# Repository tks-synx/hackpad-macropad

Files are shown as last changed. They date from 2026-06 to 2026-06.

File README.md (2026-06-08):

# hackpad-macropad

## Design Renders & Screenshots

### Macropad Design (Fusion)
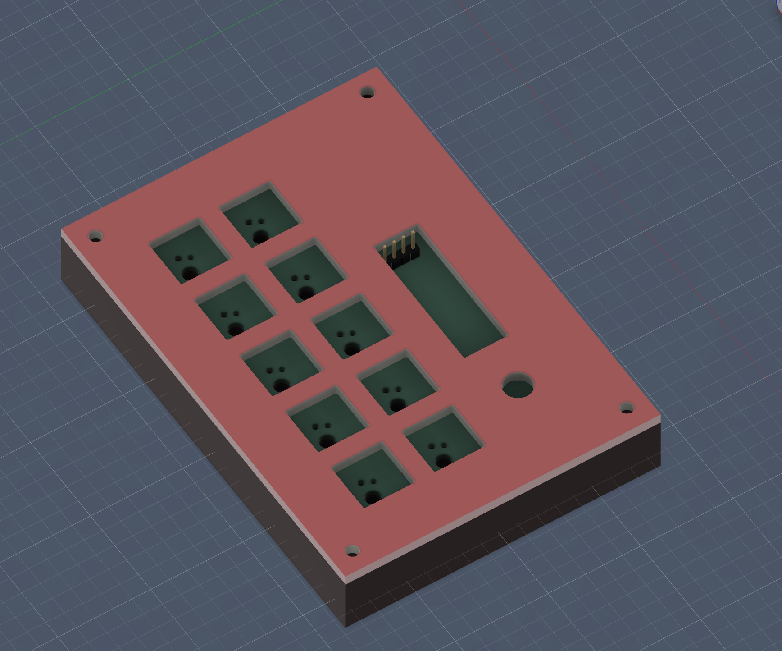
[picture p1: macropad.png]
Macropad Design

(Was not able to get the actual models for keycaps, switches, the OLED, rotator or MCU in Fusion)

### 3D Case Design (Fusion)
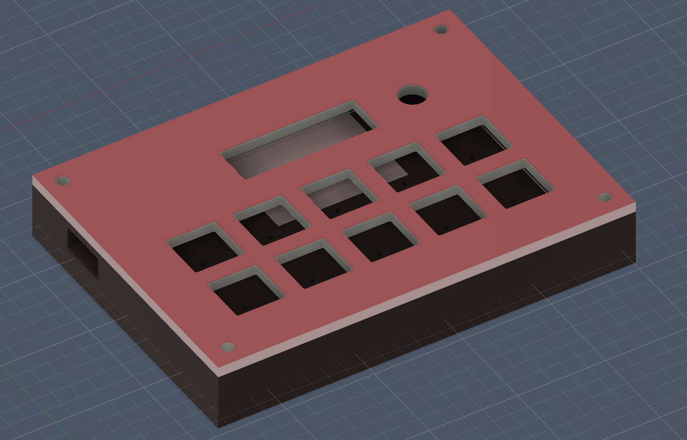
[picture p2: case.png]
Case Design


### Circuit Schematic (KiCad)
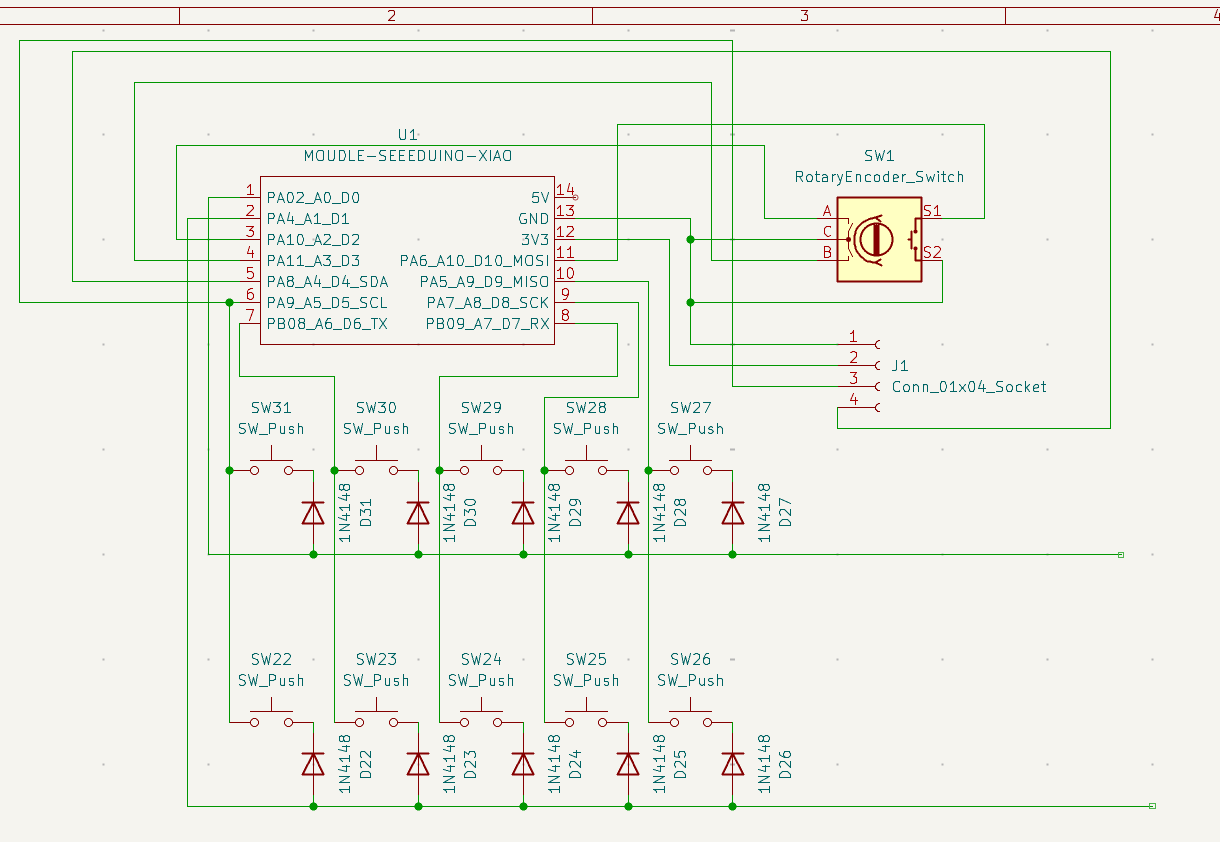
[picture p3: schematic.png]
Schematic


### PCB Layout (KiCad)
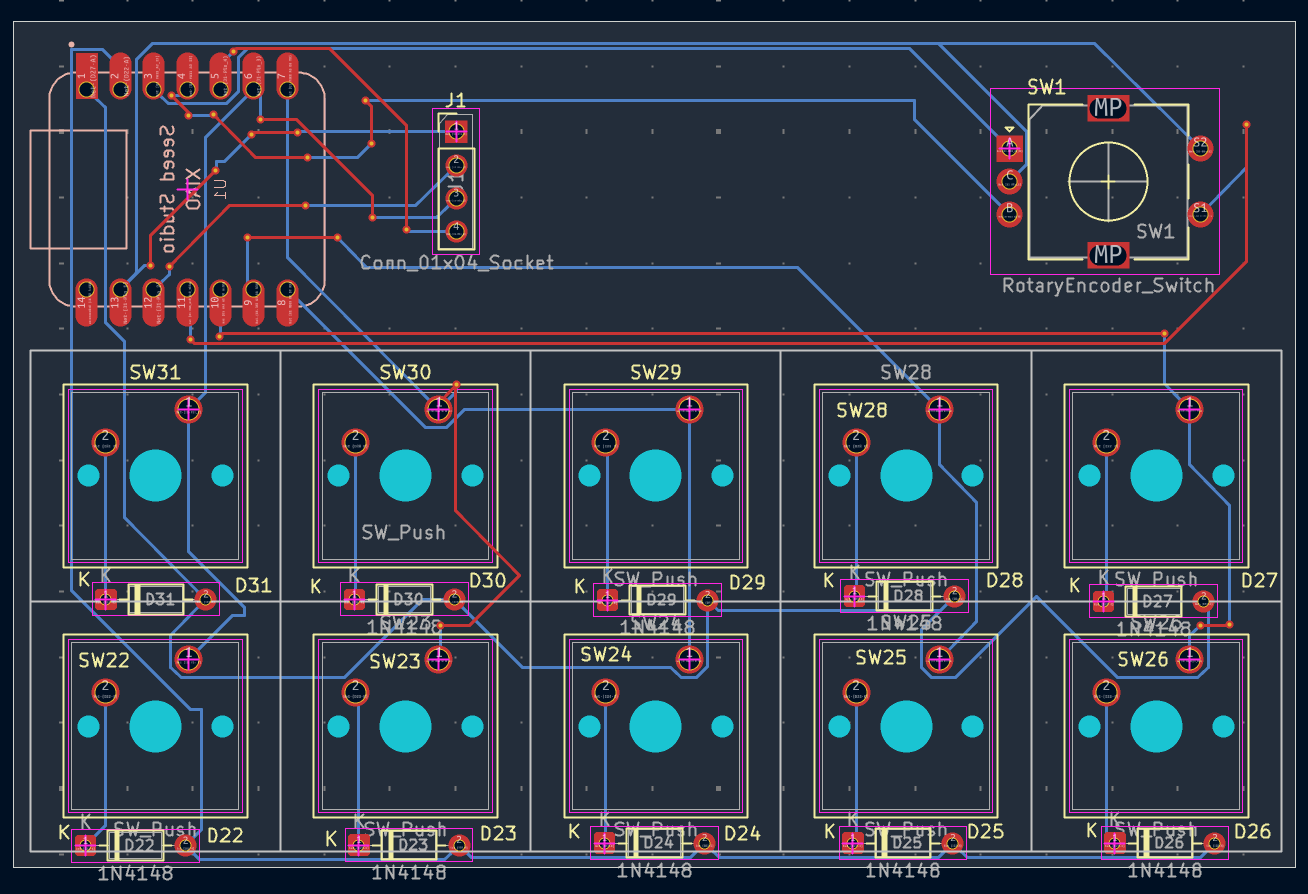
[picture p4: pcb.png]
PCB Layout


## Bill of Materials (BOM)
* [1]x Seeed XIAO RP2040 microcontroller
* [10]x MX-style mechanical switches
* [10]x Blank DSA keycaps
* [1]x 0.91” 128×32 OLED display 
* [1]x EC11 rotary encoders
* [4]x M3×16mm screws
* [4]x M3×5×4mm heatset inserts 
* 3D Printing Filament (PLA/PETG) In colour if possible

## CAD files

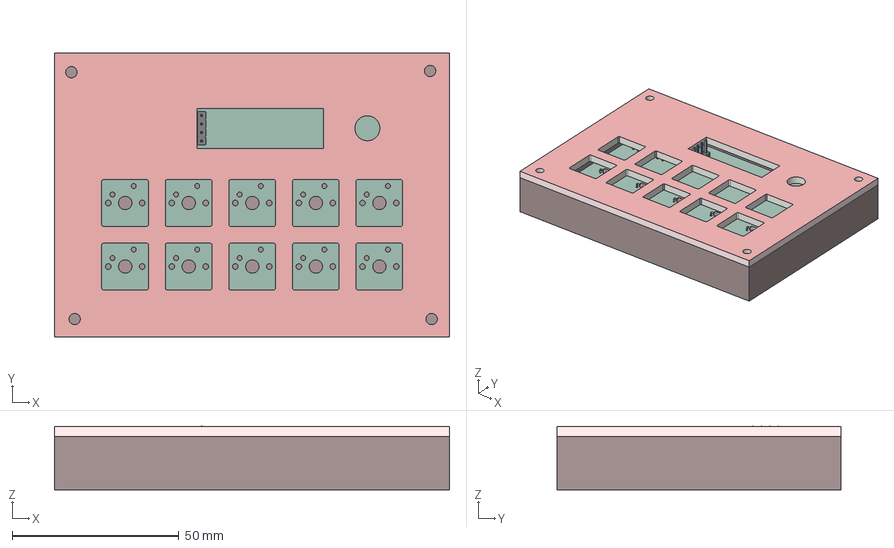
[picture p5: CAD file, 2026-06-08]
CAD/assembled-model.step
118.4 x 85.2 x 19.1 mm

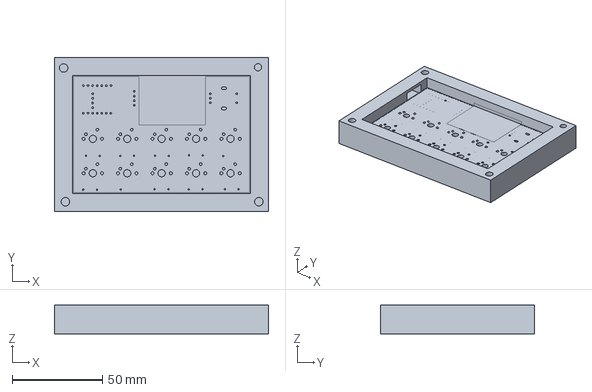
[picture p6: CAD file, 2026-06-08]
production/Bottom.step
118.4 x 85.2 x 16.0 mm

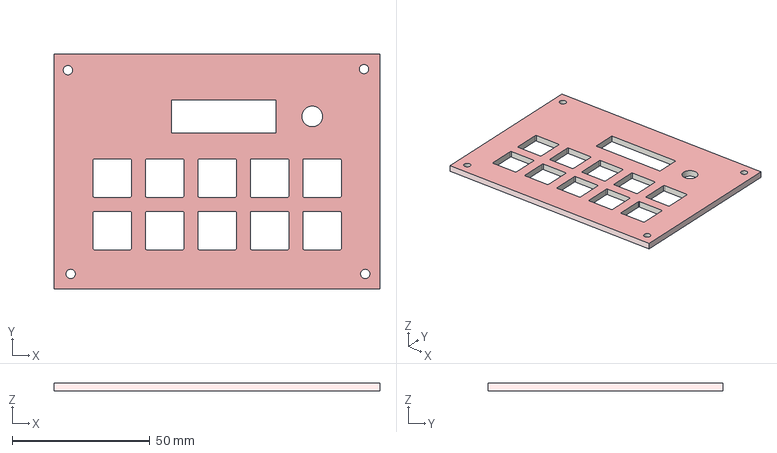
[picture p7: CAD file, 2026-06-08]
production/Top.step
118.4 x 85.2 x 3.00 mm

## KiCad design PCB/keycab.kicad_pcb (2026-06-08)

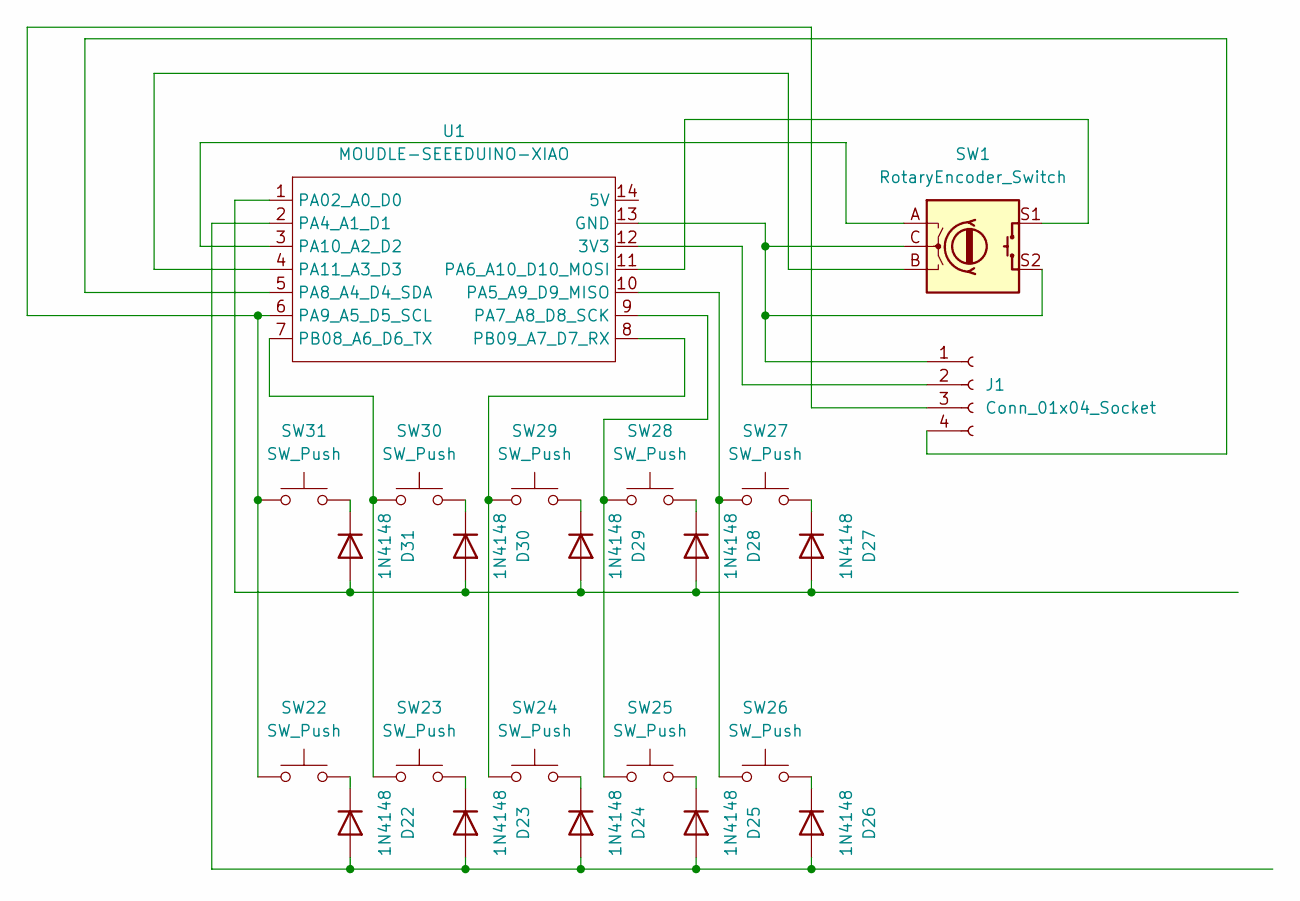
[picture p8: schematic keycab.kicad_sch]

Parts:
D22, D23, D24, D25, D26, D27, D28, D29, D30, D31: 1N4148; D_DO-35_SOD27_P7.62mm_Horizontal
J1: Conn_01x04_Socket; PinHeader_1x04_P2.54mm_Vertical
SW1: RotaryEncoder_Switch; RotaryEncoder_Alps_EC11E-Switch_Vertical_H20mm
SW22, SW23, SW24, SW25, SW26, SW27, SW28, SW29, SW30, SW31: SW_Push; SW_Cherry_MX_1.00u_PCB
U1: MOUDLE-SEEEDUINO-XIAO; XIAO-Generic-Hybrid-14P-2.54-21X17.8MM

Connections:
unnamed: D22.2 (A), D23.2 (A), D24.2 (A), D25.2 (A), D26.2 (A), U1.2 (PA4_A1_D1)
unnamed: D22.1 (K), SW22.2
unnamed: D23.1 (K), SW23.2
unnamed: D24.1 (K), SW24.2
unnamed: D25.1 (K), SW25.2
unnamed: D26.1 (K), SW26.2
unnamed: D27.2 (A), D28.2 (A), D29.2 (A), D30.2 (A), D31.2 (A), U1.1 (PA02_A0_D0)
unnamed: D27.1 (K), SW27.2
unnamed: D28.1 (K), SW28.2
unnamed: D29.1 (K), SW29.2
unnamed: D30.1 (K), SW30.2
unnamed: D31.1 (K), SW31.2
unnamed: J1.1, SW1.C, SW1.S2, U1.13 (GND)
unnamed: J1.2, U1.12 (3V3)
unnamed: J1.3, SW22.1, SW31.1, U1.6 (PA9_A5_D5_SCL)
unnamed: J1.4, U1.5 (PA8_A4_D4_SDA)
unnamed: SW26.1, SW27.1, U1.10 (PA5_A9_D9_MISO)
unnamed: SW1.S1, U1.11 (PA6_A10_D10_MOSI)
unnamed: SW25.1, SW28.1, U1.9 (PA7_A8_D8_SCK)
unnamed: SW1.A, U1.3 (PA10_A2_D2)
unnamed: SW1.B, U1.4 (PA11_A3_D3)
unnamed: SW23.1, SW30.1, U1.7 (PB08_A6_D6_TX)
unnamed: SW24.1, SW29.1, U1.8 (PB09_A7_D7_RX)

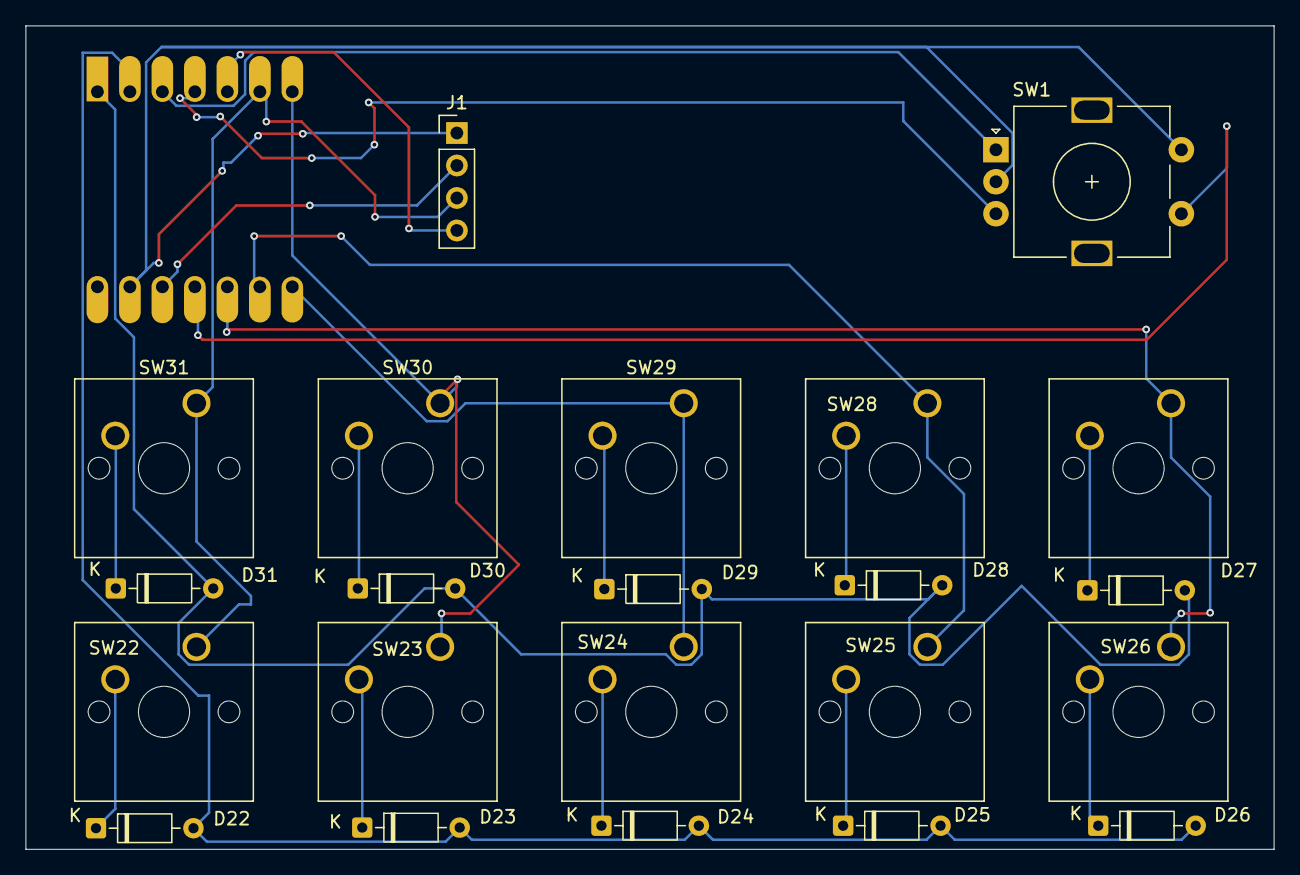
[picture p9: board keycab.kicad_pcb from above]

Board: 2 copper layers, 97.6 x 64.4 mm, 23 parts (1 on the bottom side), 23 nets.

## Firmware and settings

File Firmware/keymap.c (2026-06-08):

#include QMK_KEYBOARD_H
#include <stdio.h> // Required for sprintf formatting

/* ==========================================================================
   MACRO PAD MAC SIDE INSTALLATION & AUTOMATION BLUEPRINT
   
   PREREQUISITES:
   1. Open Terminal on your Mac and install the audio CLI tool via Homebrew:
      brew install switchaudio-source

   2. Open your favorite Mac automation utility (e.g., BetterTouchTool or 
      Keyboard Maestro) and build 5 separate triggers.

   ==========================================================================
   TRIGGER DETAILS & BASH SCRIPTS:
   ==========================================================================

   --- TRIGGER 1: KEY 10 (F13) - AUDIO DEVICE SWITCHER ---
   Type: Execute Shell Script
   Script:
      #!/bin/bash
      SwitchAudioSource -n
      NEW_DEV=$(SwitchAudioSource -c)
      XIAO_PORT=$(ls /dev/cu.usbmodem* 2>/dev/null | head -n 1)
      if [ ! -z "$XIAO_PORT" ]; then
          echo -ne "DEV:$NEW_DEV\r" > "$XIAO_PORT"
      fi

   --- TRIGGER 2: ENCODER CLOCKWISE (F14) - VOLUME UP ---
   Type: Execute Shell Script
   Script:
      #!/bin/bash
      osascript -e "set volume output volume ((output volume of (get audio status)) + 5)"
      NEW_VOL=$(osascript -e "output volume of (get audio status)")
      XIAO_PORT=$(ls /dev/cu.usbmodem* 2>/dev/null | head -n 1)
      if [ ! -z "$XIAO_PORT" ]; then
          echo -ne "VOL:$NEW_VOL%\r" > "$XIAO_PORT"
      fi

   --- TRIGGER 3: ENCODER COUNTER-CLOCKWISE (F15) - VOLUME DOWN ---
   Type: Execute Shell Script
   Script:
      #!/bin/bash
      osascript -e "set volume output volume ((output volume of (get audio status)) - 5)"
      NEW_VOL=$(osascript -e "output volume of (get audio status)")
      XIAO_PORT=$(ls /dev/cu.usbmodem* 2>/dev/null | head -n 1)
      if [ ! -z "$XIAO_PORT" ]; then
          echo -ne "VOL:$NEW_VOL%\r" > "$XIAO_PORT"
      fi

   --- TRIGGER 4: ENCODER CLOCKWISE (F16) - BRIGHTNESS UP ---
   Type: Execute Shell Script
   Script:
      #!/bin/bash
      osascript -e 'tell application "System Events" to key code 144'
      XIAO_PORT=$(ls /dev/cu.usbmodem* 2>/dev/null | head -n 1)
      if [ ! -z "$XIAO_PORT" ]; then
          echo -ne "BRT:Up\r" > "$XIAO_PORT"
      fi

   --- TRIGGER 5: ENCODER COUNTER-CLOCKWISE (F17) - BRIGHTNESS DOWN ---
   Type: Execute Shell Script
   Script:
      #!/bin/bash
      osascript -e 'tell application "System Events" to key code 145'
      XIAO_PORT=$(ls /dev/cu.usbmodem* 2>/dev/null | head -n 1)
      if [ ! -z "$XIAO_PORT" ]; then
          echo -ne "BRT:Down\r" > "$XIAO_PORT"
      fi
   ========================================================================== */

enum custom_keycodes {
    MC_RECORD = SAFE_RANGE,
    MC_KNOB_MODE 
};

// Global buffers and state trackers
char audio_device_name[32] = "Default Audio";
char alert_msg[32]         = "";
uint32_t alert_timer       = 0;

// Hardware state trackers
bool is_recording          = false; 
uint32_t record_start_time = 0;     
char timer_string[16]      = "00:00";

// Tracks what the knob currently controls (True = Volume, False = Brightness)
bool is_volume_mode        = true; 

const uint16_t PROGMEM keymaps[][MATRIX_ROWS][MATRIX_COLS] = {
    [0] = LAYOUT(
        // Row 1: Key 1 (Screenshot), Key 2 (Record), Keys 3-4 (Blank), Key 5 (Mode Toggle!)
        SCMD(KC_3),       MC_RECORD,  KC_NO,      KC_NO,        MC_KNOB_MODE,
        
        // Row 2: Keys 6-8 (Blank), Key 9 (New Note), Key 10 (Audio Switch)
        KC_NO,            KC_NO,      KC_NO,      LALT(LCMD(KC_N)), KC_F13
    )
};

void trigger_oled_alert(const char *msg) {
    strncpy(alert_msg, msg, sizeof(alert_msg) - 1);
    alert_timer = timer_read32();
}

void receive_ascii_from_host(const char *string) {
    if (strncmp(string, "DEV:", 4) == 0) {
        strncpy(audio_device_name, string + 4, sizeof(audio_device_name) - 1);
        trigger_oled_alert("Audio Switched!");
    } 
    else if (strncmp(string, "VOL:", 4) == 0 || strncmp(string, "BRT:", 4) == 0) {
        trigger_oled_alert(string); 
    }
}

bool process_record_user(uint16_t keycode, keyrecord_t *record) {
    if (record->event.pressed) {
        switch (keycode) {
            case SCMD(KC_3):
                trigger_oled_alert("Screenshot Taken");
                break;
                
            case MC_RECORD:
                if (!is_recording) {
                    tap_code16(SCMD(KC_5)); 
                    wait_ms(200); 
                    tap_code(KC_ENT); 
                    
                    is_recording = true; 
                    record_start_time = timer_read32(); 
                    trigger_oled_alert("Recording Started");
                } else {
                    tap_code16(LCTL(LCMD(KC_ESC))); 
                    is_recording = false; 
                    trigger_oled_alert("Recording Saved!");
                }
                return false; 
                
            case MC_KNOB_MODE:
                is_volume_mode = !is_volume_mode; 
                if (is_volume_mode) {
                    trigger_oled_alert("Mode: Volume");
                } else {
                    trigger_oled_alert("Mode: Brightness");
                }
                break;

            case LALT(LCMD(KC_N)):
                trigger_oled_alert("New Apple Note");
                break;
                
            case KC_F13:
                trigger_oled_alert("Switching Audio...");
                break;
        }
    }
    return true;
}

#ifdef ENCODER_ENABLE
bool encoder_update_user(uint8_t index, bool clockwise) {
    if (index == 0) {
        if (is_volume_mode) {
            if (clockwise) { tap_code(KC_F14); } 
            else           { tap_code(KC_F15); }
        } else {
            if (clockwise) { tap_code(KC_F16); } 
            else           { tap_code(KC_F17); }
        }
    }
    return true;
}
#endif
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

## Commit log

2026-06-08 feat: successfully compiled macropad layout firmware
    [Bottom.step, Top.step]
2026-06-08 docs: fix readme image paths and finalize submission assets
    [assembled-model.step, keycab.step]
